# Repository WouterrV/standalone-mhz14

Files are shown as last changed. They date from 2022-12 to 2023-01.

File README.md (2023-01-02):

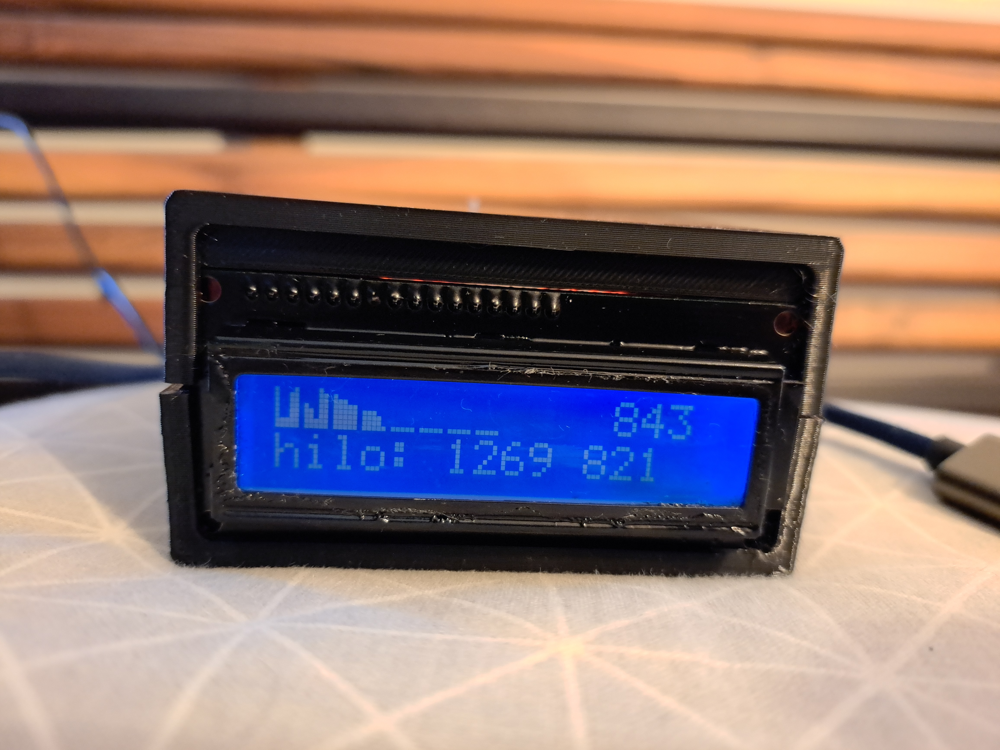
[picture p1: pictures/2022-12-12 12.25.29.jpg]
Finished product


# Standalone-mhz14
A standalone CO<sub>2</sub> display based on Arduino and the MH-Z14 sensor, for checking if the ventilation in a living space is OK, because elevated CO2 levels seem to impair cognition. 

I wanted to buy a commercial CO2 sensor but almost all of those are very vague on how calibration happens, or don't even specify the type of sensor used (NDIR, extrapolation based on VOC), let alone the sensor model. Exceptions to that are quite (>$120) expensive, but available - MoreSense for €120, Aranet4 for $250. As I wanted to build multiple sensor it made sense to DIY it.

# Why ABC is off in the Arduino sketch
Automatic Baseline Calibration is disabled, because ABC gives a false sense of accuracy. Let me explain:  take a room with people, the CO<sub>2</sub> will be elevated. Now if the (ventilated) room gets empty, CO<sub>2</sub> readings will decrease, with an asymptote at ~400 ppm. If this asymptote happens according to the sensor at let's say 500 ppm, you know the sensor is in need of calibration, because the outside is ~400 ppm (see satellite imagery of that [here](https://atmosphere.copernicus.eu/temperatures-wildfires-and-co2-copernicus-europes-eyes-earth-observes-year-extremes)).

The MH-Z14 sensor correlates infrared transmittance in air to a certain CO<sub>2</sub> value. Because both the offset and the slope of this relationship can shift with sensor aging, say by the LED getting dimmer, it's unclear if just removing a Y offset (which is how the sensor seems to do calibration, see [here](https://wolles-elektronikkiste.de/en/mh-z14-and-mh-z19-co2-sensors)) in our example, doing -100 to our reading of 500 to end up at 400 again) made things better. It might be that it wasn't the offset, but the slope that needed adjustment. Thus I think that it's better to leave readings uncalibrated, and look at the asymptote as a sanity check to see if the sensor is still 'good', because if it's ~400 in a well-ventilated room then both the slope and the offset must be correct.

When it does need calibration, a span (two point) calibration can be done with either test gases or a calibrated sensor.

# Graphs
The LCDGraph library is used for graphs, but the standard and cheap 16 character * 2 rows displays aren't very well suited to graphs, because of the grap between characters, and the 8 custom characters limit. A 128*64 OLED for a few dollars might be a better fit.

# Enclosure
Generated by an openSCAD file, credits go to [jbebel](https://github.com/jbebel/Ultimate-Box-Maker).

# Accuracy
At ~500 ppm and ~2000 ppm, it seems that the readings fall within 200 ppm of my MoreSense with a SenseAir s8 sensor, which is good enough for me.

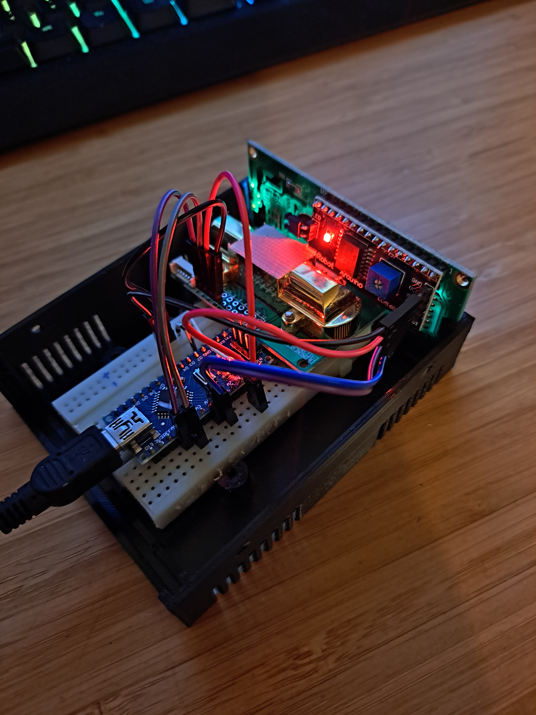
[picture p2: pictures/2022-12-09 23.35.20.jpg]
half open enclosure


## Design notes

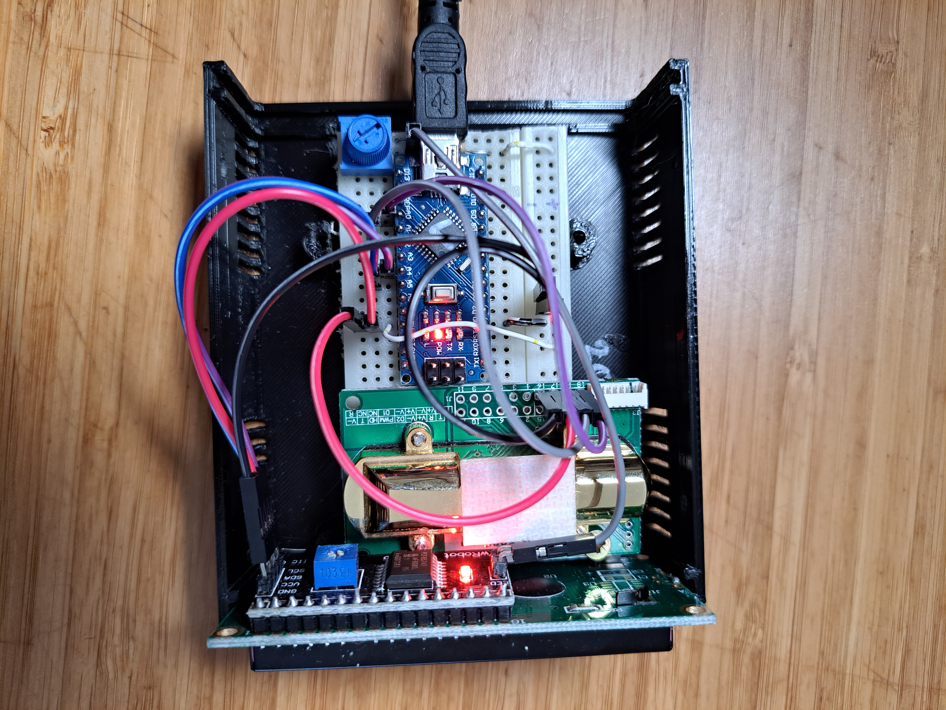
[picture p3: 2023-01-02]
pictures/2022-12-10 14.46.39.jpg

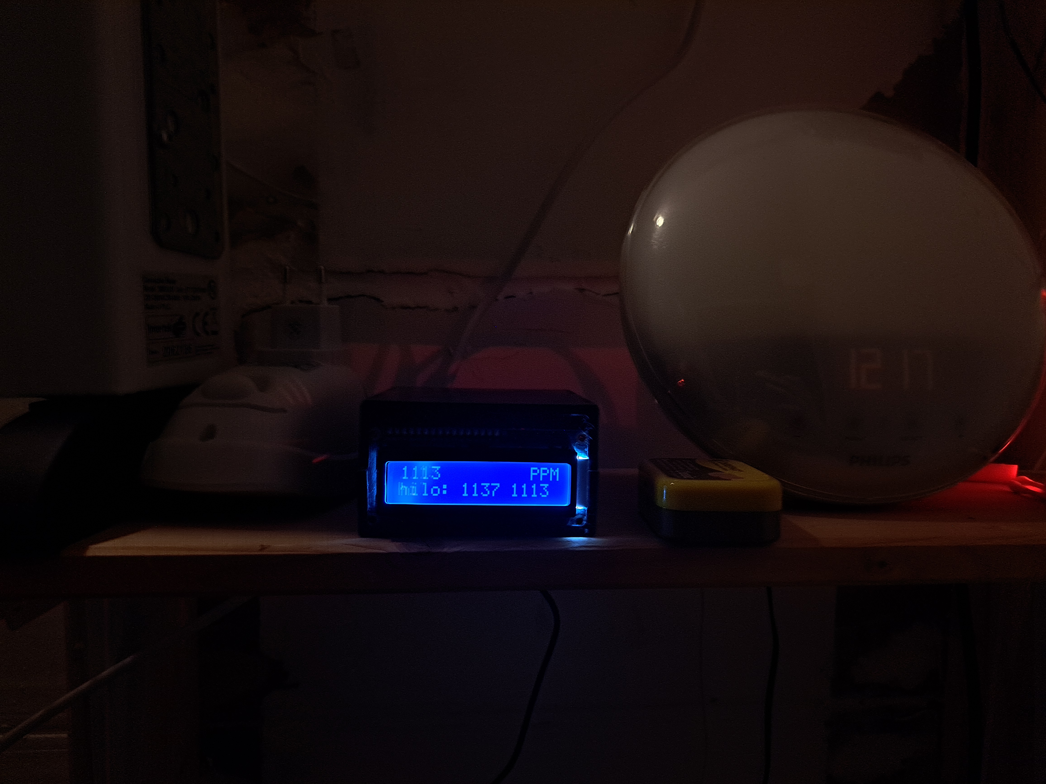
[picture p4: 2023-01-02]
pictures/2022-12-10 12.18.43.jpg

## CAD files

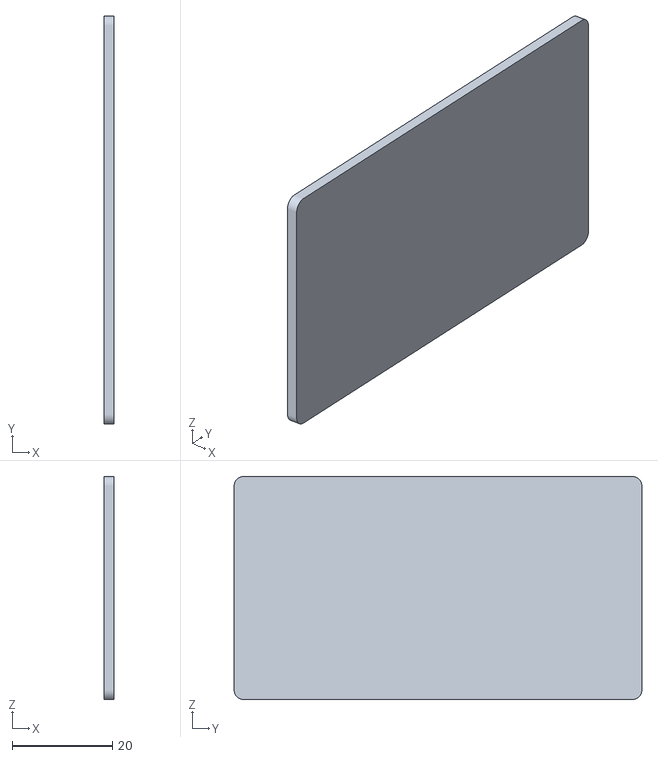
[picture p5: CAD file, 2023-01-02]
enclosure/Ultimate_Box mk1 panel.stl
2.00 x 81.2 x 44.4

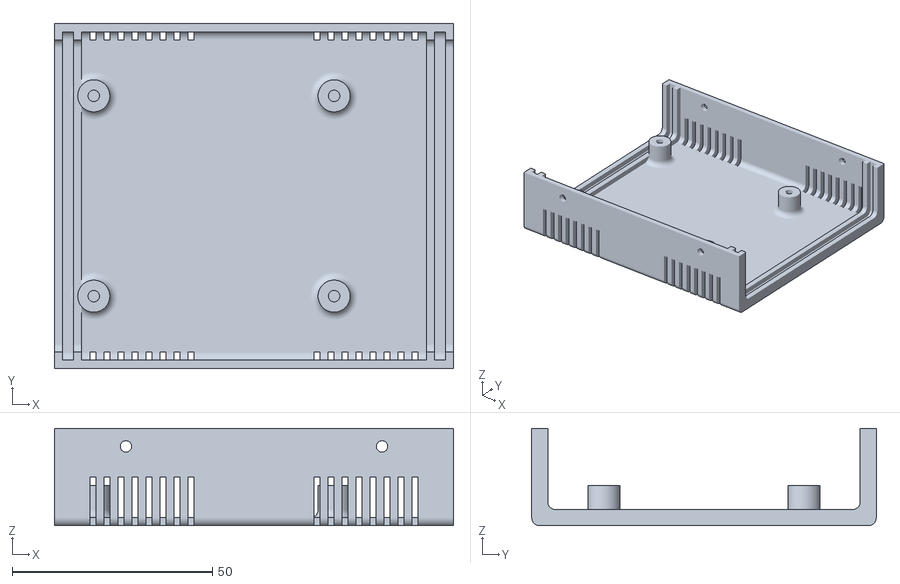
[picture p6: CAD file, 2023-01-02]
enclosure/Ultimate_Box mk1 bottom.stl
99.6 x 86.0 x 24.3

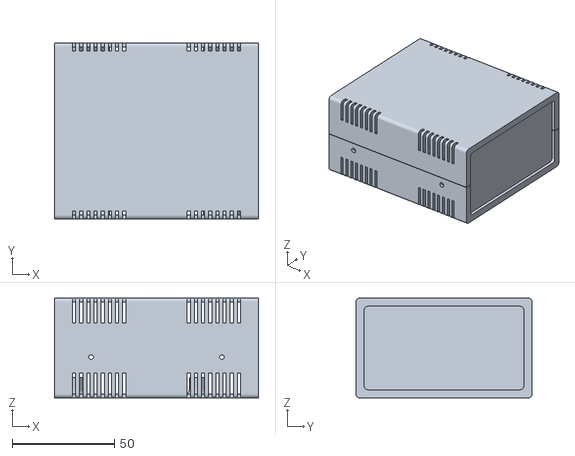
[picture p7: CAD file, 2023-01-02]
enclosure/Ultimate_Box mk1.stl
99.6 x 86.0 x 48.8

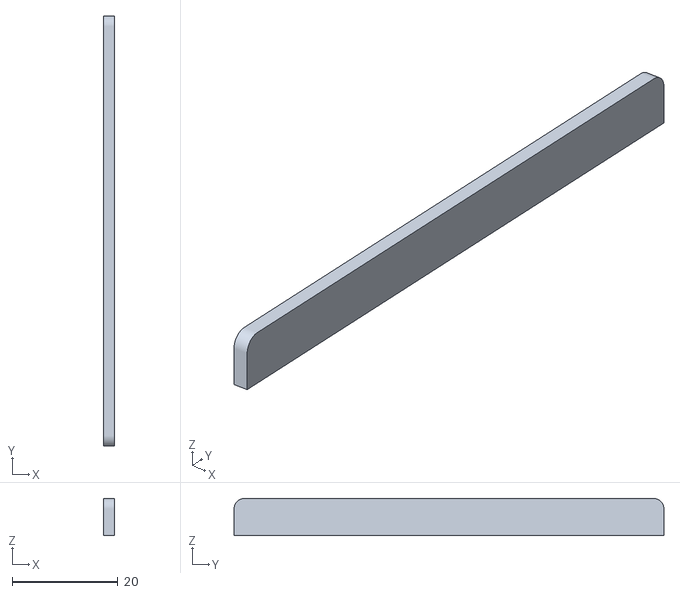
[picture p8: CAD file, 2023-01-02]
enclosure/Ultimate_Box mk1 panel - 7mm plate.stl
2.00 x 81.2 x 7.00

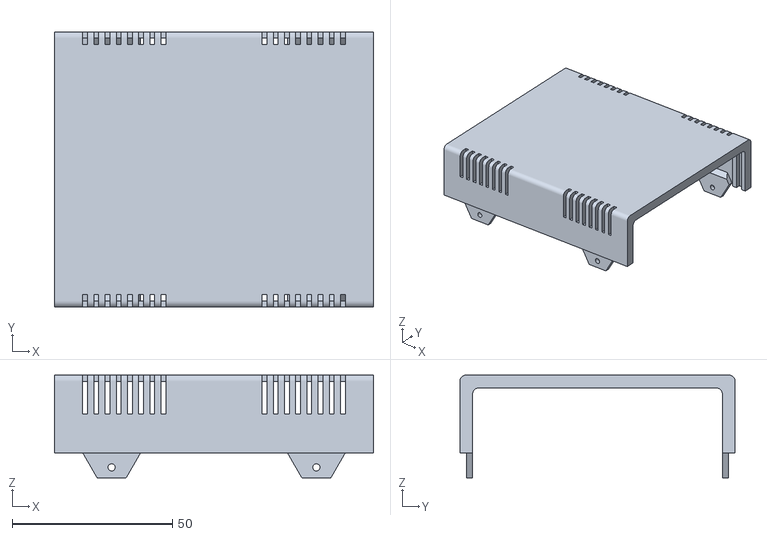
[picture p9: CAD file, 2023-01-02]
enclosure/Ultimate_Box mk1 top.stl
99.6 x 86.0 x 32.1

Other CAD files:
enclosure/Ultimate_Box.scad

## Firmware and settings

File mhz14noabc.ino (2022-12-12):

#include <SoftwareSerial.h>
#include <SPI.h>
#include <Wire.h>

// https://github.com/rlogiacco/CircularBuffer
#include <CircularBuffer.h>
CircularBuffer<int, 40> circularBuffer;

// we want 24h on the display, 16 chars * 5 values = 80, 24/80=0.3 hours every measurement, 18 minutes
// eh we only have 8 chars. 8*5=40, 24*60/40=36 min per measurement

#include <hd44780.h>                       // main hd44780 header
#include <hd44780ioClass/hd44780_I2Cexp.h> // i2c expander i/o class header
#include <LCDGraph.h> // see https://github.com/jgOhYeah/LCDGraph/blob/main/examples/I2CDisplay/I2CDisplay.ino

hd44780_I2Cexp lcd; // declare lcd object: auto locate & auto config expander chip

// specifying 2 char high doesnt seem to work, is still 1
// width >8 also doesnt work, nothing gets displayed
// limit here is the 8 custom chars. And when we change a char then the past drawings of that charget updated
LCDGraph<uint8_t, hd44780_I2Cexp> graph1(8, 1, 0); // 8 character wide graph, 1 char high, starting at custom char # 0 in the lcd ram.


// LCD geometry
const int LCD_COLS = 16;
const int LCD_ROWS = 2;

#define INTERVAL 5000
#define MH_Z19_RX A0 // RX
#define MH_Z19_TX A1 // TX

// Adapted from https://www.letscontrolit.com/forum/viewtopic.php?t=1785&start=40
// but I dont believe in single point calibration (two point is much more legit) so I disabled Automatic Baseline Calibration (ABC) as much as possible
// can be verified by running the setup for more than 24h in a >400ppm environment and verifying a drop due to ABC doesnt occur
// calibration is still doable by connecting pins on the sensor
// other changes: dont delay for 3 minutes, send co2 value immediately, we can ignore those readings on the PC, its nice to see the warming up happen

byte mhzResp[9];    // 9 bytes bytes response
byte mhzCmdReadPPM[9] = {0xFF, 0x01, 0x86, 0x00, 0x00, 0x00, 0x00, 0x00, 0x79};
byte mhzCmdCalibrateZero[9] = {0xFF, 0x01, 0x87, 0x00, 0x00, 0x00, 0x00, 0x00, 0x78};
byte mhzCmdABCEnable[9] = {0xFF, 0x01, 0x79, 0xA0, 0x00, 0x00, 0x00, 0x00, 0xE6};
byte mhzCmdABCDisable[9] = {0xFF, 0x01, 0x79, 0x00, 0x00, 0x00, 0x00, 0x00, 0x86};
byte mhzCmdReset[9] = {0xFF, 0x01, 0x8d, 0x00, 0x00, 0x00, 0x00, 0x00, 0x72};
byte mhzCmdMeasurementRange1000[9] = {0xFF, 0x01, 0x99, 0x00, 0x00, 0x00, 0x03, 0xE8, 0x7B};
byte mhzCmdMeasurementRange2000[9] = {0xFF, 0x01, 0x99, 0x00, 0x00, 0x00, 0x07, 0xD0, 0x8F};
byte mhzCmdMeasurementRange3000[9] = {0xFF, 0x01, 0x99, 0x00, 0x00, 0x00, 0x0B, 0xB8, 0xA3};
byte mhzCmdMeasurementRange5000[9] = {0xFF, 0x01, 0x99, 0x00, 0x00, 0x00, 0x13, 0x88, 0xCB};

int shifts = 0, co2ppm;

long previousMillis = 0;
long previous18minMillis = 9990000; // so we start immediately with filling our circular buffer

SoftwareSerial co2Serial(MH_Z19_RX, MH_Z19_TX); // define MH-Z19

byte checksum(byte response[9]) {
  byte crc = 0;
  for (int i = 1; i < 8; i++) {
    crc += response[i];
  }
  crc = 255 - crc + 1;
  return crc;
}


void disableABC() {
  co2Serial.write(mhzCmdABCDisable, 9);
}

int readCO2() {
  byte cmd[9] = {0xFF, 0x01, 0x86, 0x00, 0x00, 0x00, 0x00, 0x00, 0x79};
  byte response[9];
  co2Serial.write(cmd, 9);
  // The serial stream can get out of sync. The response starts with 0xff, try to resync.
  while (co2Serial.available() > 0 && (unsigned char)co2Serial.peek() != 0xFF) {
    co2Serial.read();
    shifts++;
  }

  memset(response, 0, 9);
  co2Serial.readBytes(response, 9);

  for (int i = 0; i < 9; i++) {
    Serial.print(" 0x");
    Serial.print(response[i], HEX);
  }
  Serial.println(" Response OK. Shifts=" + String(shifts));


  if (response[1] != 0x86)
  {
    Serial.println(" Invalid response from co2 sensor!");
    return -1;
  }

  if (response[8] == checksum(response)) {
    int responseHigh = (int) response[2];
    int responseLow = (int) response[3];
    int ppm = (256 * responseHigh) + responseLow;
    return ppm;
  } else {
    Serial.println("CRC error!");
    return -1;
  }
}

void setup() {
  Serial.begin(115200);
  unsigned long previousMillis = millis();
  co2Serial.begin(9600); //Init sensor MH-Z19(14)

  int status;

  status = lcd.begin(LCD_COLS, LCD_ROWS);

  //  This gives a fatalError
  //  status = lcd2.begin(LCD_COLS, LCD_ROWS);
  if (status) // non zero status means it was unsuccesful
  {

    Serial.println("fatal 44780 error");
    // hd44780 has a fatalError() routine that blinks an led if possible
    // begin() failed so blink error code using the onboard LED if possible
    //    hd44780::fatalError(status); // does not return
  }

  // initalization was successful, the backlight should be on now

  // Print a message to the LCD
  //  setBacklight doesn't seem to work, either with the jumper in/out
  lcd.backlight();
  lcd.setBacklight(200);
  lcd.print("MH-Z14 ABC disab");

  // start graph
  graph1.begin(&lcd);

  // Draw the graph:
  graph1.yMin = -800;
  graph1.yMax = 800;
  graph1.filled = true;
  graph1.setRegisters();

  delay(500);
  disableABC();
}

int lowco2 = 9999;
int highco2 = 0;
boolean hasWarmedUp = 0;
boolean displayGraph = 0;

void loop() {
  unsigned long currentMillis = millis(); // overflows after 50 days, but with abs we avoid overflow issues, we measure difference either way

  // Only do something every interval
  if (abs(currentMillis - previousMillis) > INTERVAL)
  {
    previousMillis = currentMillis;

    // Set warmed up status
    if (currentMillis > 180000) {
      hasWarmedUp = true;
    }

    Serial.print("Requesting CO2 concentration...");
    co2ppm = -999;
    co2ppm = readCO2();
    Serial.println("  PPM = " + String(co2ppm));

    // circularBuffer maintenance every 36 mins
    if (abs(currentMillis - previous18minMillis) > 2160000) {
      previous18minMillis = currentMillis;

      circularBuffer.push(co2ppm);
      graph1.add(co2ppm);

      // read from circularBuffer with []
      // dump it to serial to see if it works
      for (byte i = 0; i < circularBuffer.size(); i++) {
        Serial.print(circularBuffer[i]);
        Serial.print(" ");
      }
    }

    // Update high/low if sensor is warmed up
    if (hasWarmedUp) {
      if (co2ppm > highco2) {
        highco2 = co2ppm;
      }
      if (co2ppm < lowco2 && co2ppm != 410 && co2ppm != -1) {
        lowco2 = co2ppm;
      }
    }

    // Print both graph and text
    lcd.clear();

    // Graph
    graph1.autoRescale(true); // rescale based on values in the circular buffer it seems
    graph1.setRegisters();
    graph1.display(0, 0);

    // Text
    lcd.setCursor(12, 0);
    lcd.print(co2ppm);
    // LCD print high, low
    lcd.setCursor(0, 1);
    if (hasWarmedUp) {
      lcd.print("hilo: " + String(highco2) + " " + String(lowco2));
    } else
    {
      lcd.print("3 min warmup...");
    }



  }
}

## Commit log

2022-12-09 last commit before switching to i2c screen
2022-12-12 36min sampled 24h graph 8 char wide working
2023-01-02 feat: add enclosure
    [Ultimate_Box mk1 bottom.stl, Ultimate_Box mk1 panel - 7mm plate.stl, Ultimate_Box mk1 panel.stl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]
